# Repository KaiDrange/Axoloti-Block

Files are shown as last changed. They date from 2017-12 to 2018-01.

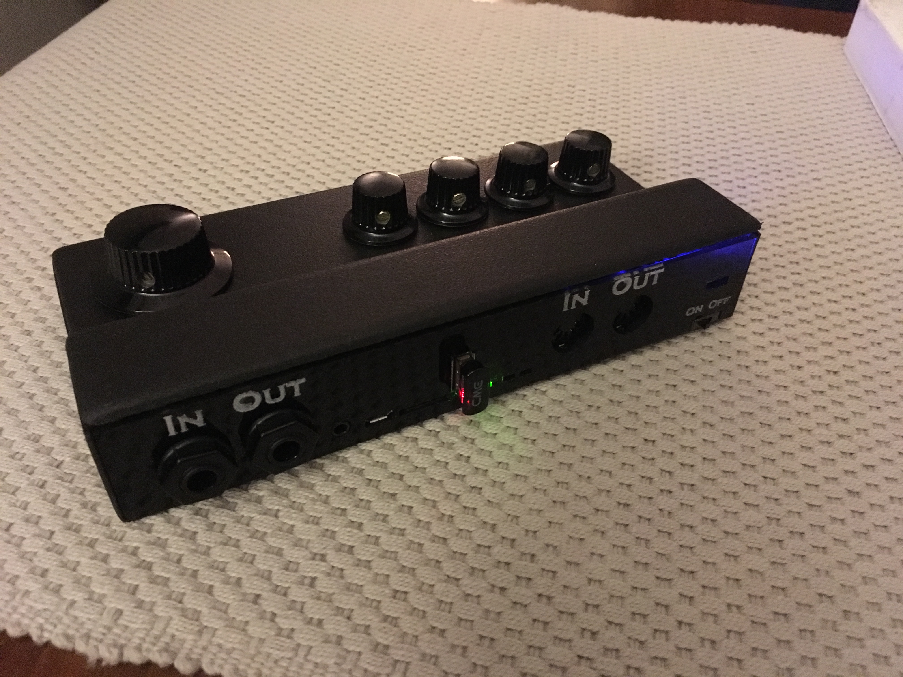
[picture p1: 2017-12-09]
AxolotiBlock_photo.jpg

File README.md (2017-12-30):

# Axoloti-Block
Axoloti hardware synth for the Roli Blocks system

It is a 3D printed axoloti enclosure with an acrylic laser cut front panel, battery power, five potmeters and four pushbuttons. Dimensions are the same as two Roli Lightpad Blocks next to each other. Magnets in the enclosure means the Blocks snaps neatly to the Axoloti.

I normally use a CME Widi Bud in the USB Host port of the Axoloti for wireless Bluetooth midi to/from the Roli Blocks, but USB cable works as well. But note that the Widi Bud will choke on large amounts of midi data, resulting in hanging notes, etc. Three simultaneous keys with full expression works well, so the Widi Bud is OK for "simple" playing.

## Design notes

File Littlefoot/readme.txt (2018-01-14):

Littlefoot scripts that runs on the Roli Blocks.

The Seaboard block script toggles between MPE mode and single channel mode with the Mode key.
Midi CC 80 sets midi channel (channel 0 = MPEMode)
Midi CC 81 Sets "piano mode" where slides trigger notes and expression is turned off. 0 = off, 1 = on.

When the Seaboard connects to a host, it sends CC 61. The seaboard object for Axoloti will then reply with the CCs for the settings used for the currently running patch.

The lightpad block script is for a "note grid" of 1x1, 2x2, 4x4 or 5x5 squares. It also displays numbers.
CC 70 for midi channel (channel 0 = MPE mode)
CC 71 displays a one or two digit number
CC 72 sets grid size (1, 2, 4 or 5)

Similar to the Seaboard script, it sends midi CC 60 when it connects to a host to request current settings.

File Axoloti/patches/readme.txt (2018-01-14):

BlocksProgramChanger.axs - Controller subpatch (add it to Axoloti preferences) that cycles through the patches with two of the pushbuttons. It will send the new patch number to the lightpad block as midi CC 71 so that it can display it. 

BlocksControls.axs - subpatch for the hardware knobs and buttons (except the two pushbuttons used for cycling through patches)

BlocksFX.axp - My default startup patch. It is a simple fx patch with chorus, delay and reverb applied to a mono input. It also routes non-MPE midi from the Seaboard block to the DIN output. All expression and CCs are removed so that it behaves like a normal, simple midi keyboard. A connected lightpad block works as a midi XYZ pad. Two of the AxoBlock pushbuttons set the output midi channel.

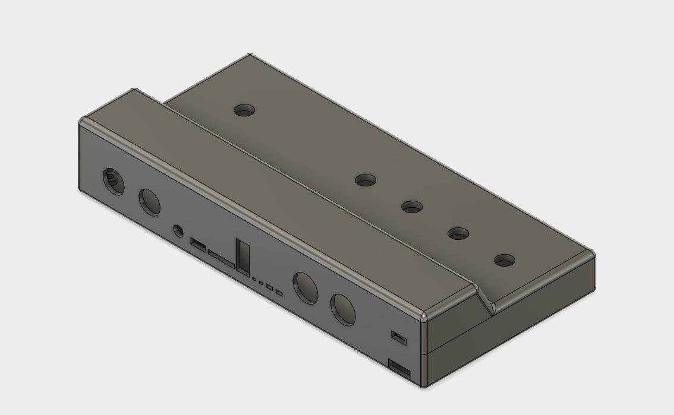
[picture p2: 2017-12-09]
AxolotiBlock_render.jpg

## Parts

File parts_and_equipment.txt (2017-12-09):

I used:
2mm thick transparent acrylic PMMA for the panel with connections. Thicker than 2mm would probably make some of the IO hard to use. (I also used this as a mounting board for the potmeters)

PLA filament for 3D printing the case.

Five 9mm VERTICAL: B25K - 25K Linear potmeters:
https://www.thonk.co.uk/shop/alpha-9mm-pots/

Four "Fine - Small" and one "Fine - XL" of these knobs
https://www.thonk.co.uk/shop/davies-skirted-knobs/

Adafruit Powerboost 1000C
https://learn.adafruit.com/adafruit-powerboost-1000c-load-share-usb-charge-boost/overview

An SPDT Slide switch
https://www.adafruit.com/product/805

A flat 3.7v 2000mAh Lithium Ion Polymer Battery
https://www.digitalimpuls.no/pc-komponenter/enkortsdata/arduino/diverse/lithium-ion-polymer-battery-37v-2000mah-141844-p0000158591

Four small pushbuttons. I don't know where I got them, but they looked like these, only black:
https://www.adafruit.com/product/1489

M3 and M2 countersunk screws and nuts.

White acrylic paint for the engraved text on the acrylic panel (before the black spray)

Black acrylic spray paint for the acrylic panel (after painting the engraved sections white)

Black Plasti Dip rubber spray for the 3D printed case.

Five 10x10mm square neodymium magnets (three in front, one on each side)

Super-glue

A dremel to drill holes for M3 screws and notches for the magnets in the acrylic mounting board I attached the pots to.

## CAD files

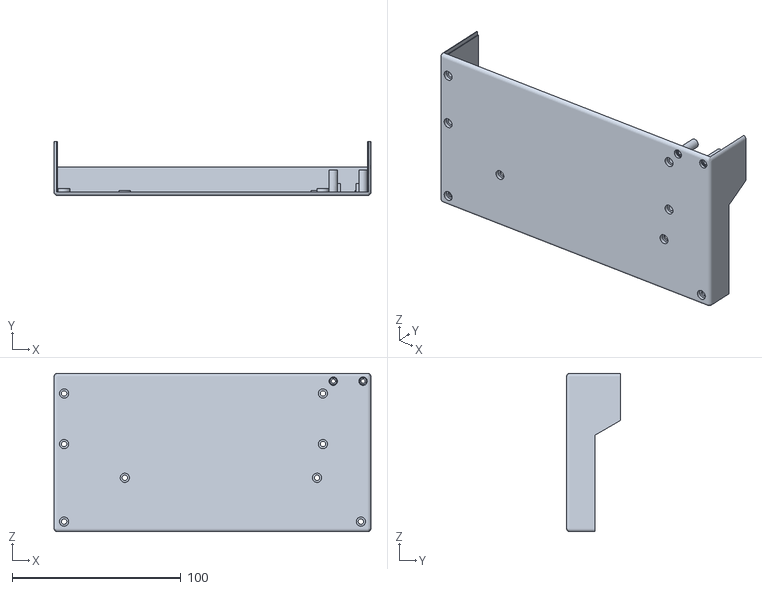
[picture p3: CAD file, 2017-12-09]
bottom.stl
188.0 x 32.0 x 94.0

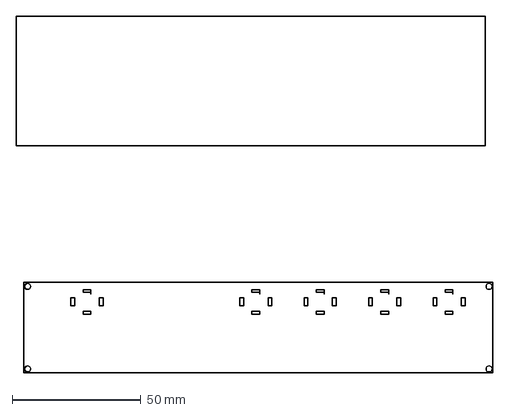
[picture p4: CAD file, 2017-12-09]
potmeter_plate.dxf
185.0 x 138.2 mm

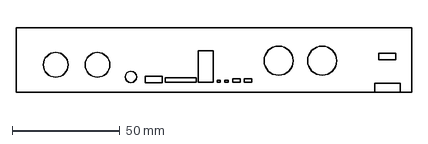
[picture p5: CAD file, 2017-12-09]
front.dxf
184.0 x 30.0 mm

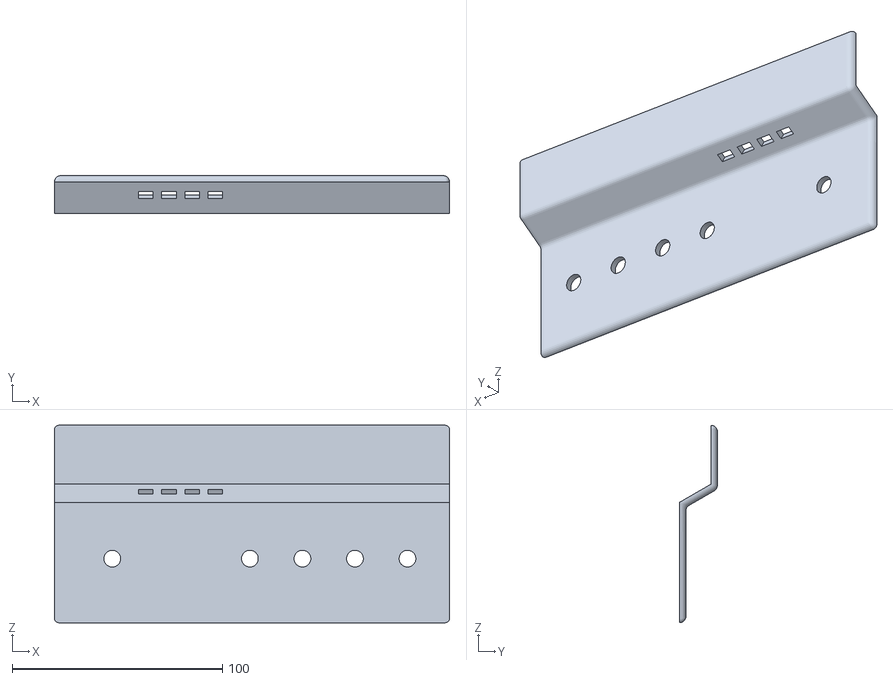
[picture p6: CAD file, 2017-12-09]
lid.stl
188.0 x 18.0 x 94.0

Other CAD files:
AxolotiBlock_Fusion360.f3d
